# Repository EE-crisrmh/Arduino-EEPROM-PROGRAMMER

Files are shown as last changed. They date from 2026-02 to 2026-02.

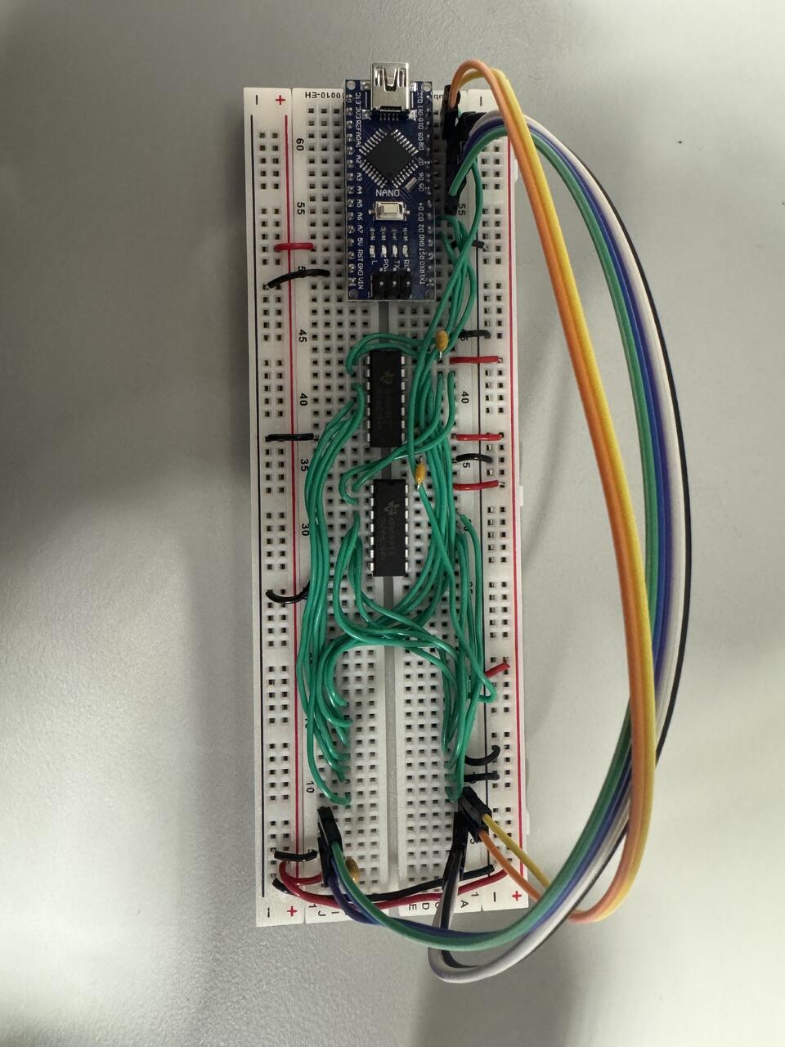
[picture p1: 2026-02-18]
Doc/Prgrammer_Breadboard_Prototype.jpeg

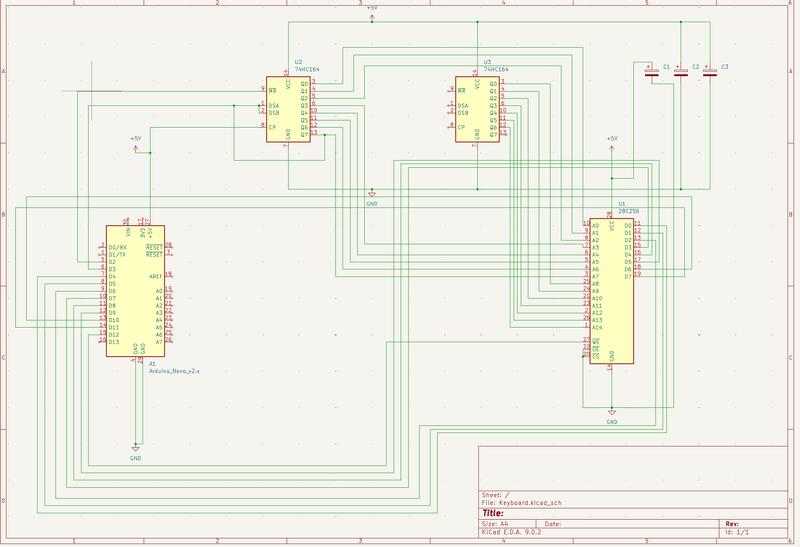
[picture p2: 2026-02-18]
Doc/Schem_pic.jpeg

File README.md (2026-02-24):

# AT28C256 EEPROM Programmer (macOS-friendly)

A standalone EEPROM programmer built to support rapid ROM iteration for a 6502 computer without relying on Windows-only tooling.  
This project uses an **Arduino nano** and **2x shift registers** to drive the EEPROM address bus, perform **parallel byte writes**, and run **read-back verification** to ensure data integrity.

This repo contains:
- The **firmware** that runs on the Arduino and directly controls the EEPROM.
- A **host-side tool spec** (macOS) to upload `.bin` images over USB serial, similar to a minimal “TL48 workflow,” but focused on AT28C256.

---

## Why this exists

I purchased a TL48 programmer but the workflow was not reliable on my macOS. Rather than depend on Windows software, I built a dedicated programmer that:
- Works over standard USB serial
- Supports full-chip programming + verify
- Fits the actual needs of a 6502 ROM development loop

---

## System Architecture

### Hardware (high-level)
- **Arduino Nano** orchestrates all control and timing.
- **Shift registers** generate the full address bus while minimizing GPIO usage.
- **Parallel data bus** is driven directly for byte writes and reads.
- Control signals (WE/OE/CE) are toggled with correct timing for AT28C256 write cycles.

### Firmware responsibilities (Arduino)
The Arduino firmware is responsible for:
- Setting an address (`setAddress(addr)`)
- Writing a byte (`writeByte(addr, value)`)
- Reading a byte (`readByte(addr)`)
- Verifying a block or entire chip (`verify(image)`)

### Host tool responsibilities (macOS)
The host tool is responsible for:
- Loading a ROM image (`.bin`)
- Sending commands/data to the Arduino over USB serial
- Displaying progress + errors
- Optionally doing a second-pass verify for confidence

---

## Features

- **AT28C256 support**
- **Byte-level programming**
- **Read-back verification**
- **Deterministic timing control**
- Designed for a fast ROM iteration loop (edit → build → flash → test)

---

## Host Tool: How a Software Developer can contribute: (More in Future Plans folder) 

The goal is a small CLI tool that feels like:

```bash
eeprom flash firmware.bin
eeprom verify firmware.bin
eeprom read dump.bin
eeprom info

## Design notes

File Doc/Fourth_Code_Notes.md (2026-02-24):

# EEPROM Programmer — Lab Notes

## Date
2026-02-24

---

## Objective
Stabilize the address generation subsystem and migrate the control architecture from Arduino Nano → standalone ATmega328P design for PCB.

---

## What Was Built and Tested

### 1. Breadboard Prototype — 74HC164 Shift Register Chain
- Device: 74HC164 ×2
- Verified functional as a 16-bit shift chain

#### Wiring (per datasheet pinout)
For each 74HC164:
- VCC (14) → +5V
- GND (7) → GND
- CLK (8) → SR_CLK
- CLR (9) → SR_CLR
- A (1) and B (2) tied together

Chain:
- Chip1 QH (13) → Chip2 A+B

Control from MCU:
- SR_DATA → serial data in (chip1 A+B)
- SR_CLK → common clock
- SR_CLR → common clear

Decoupling:
- 0.1 µF per IC

#### Test Method
Firmware patterns:
- Walking 1
- Block fill / flush

#### Result
- Bit propagation confirmed across both ICs
- Visual verification using LEDs on QA outputs
- Chain direction and timing confirmed

---

### 2. ATmega328P Standalone Architecture (Schematic Complete)
- Package: DIP-28
- Programming method: ISP only
- Clock source: internal oscillator (no crystal)

#### Power
- VCC (7), AVCC (20) → +5V
- GND (8), GND (22) → GND
- AREF → 0.1 µF → GND
- 0.1 µF decoupling on VCC and AVCC
- 10 µF bulk on 5V rail

#### Reset
- 10k pull-up to +5V
- Reset pushbutton to GND
- Reset routed to ISP

#### ISP Header (2×3)
- MISO → PB4 (18)
- MOSI → PB3 (17)
- SCK → PB5 (19)
- RESET → pin 1
- VCC, GND

#### Shift Register Control Pins
- SR_DATA → PD2 (pin 4)
- SR_CLK  → PD3 (pin 5)
- SR_CLR  → PD4 (pin 6)

#### Power Input
- External +5V and GND connector
- Bulk cap at entry
- Power LED

#### Debug
- Status LED on PB0

---

## Problems Encountered
- Grid misalignment in KiCad causing false net connectivity
- Hidden power pins in MCU symbol
- Initial clock/data misrouting on shift registers
- Breadboard short during second SR integration → thermal event → corrected by staged reassembly

---

## Verified Working Today
- 16-bit shift chain hardware
- Correct bit propagation
- Clean MCU schematic with ERC passing
- ISP net connectivity

---

## Next Step
Return to breadboard prototype and integrate EEPROM:
- Reintroduce data bus
- Reintroduce /CE /OE /WE control
- Perform address-line validation using proven shift chain

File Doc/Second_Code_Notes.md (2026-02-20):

# Notes — EEPROM Programmer Prototype Debug Log

## Date
2026-02-18

## Goal of today
1) Address shifting works (the EEPROM address changes when I shift different bits)
2) Data bus mapping is correct (D0–D7 are actually the bits I think they are)
3) Writes actually program the EEPROM (not just “I sent a write command”)
4) Reads are stable and repeatable
5) The test interface works reliably (serial commands / batch commands)

## Context
A key complication is that EEPROM I/O3 (data bit 3) is physically broken on my current chip. Because of that, I mask out bit 3 (0x08) during comparisons. This lets me validate the other 7 bits even with the damaged pin.

---

## Test 1 — Baseline read stability at a fixed address
### What I did
I read address `0x0000` repeatedly using the serial read command.

Example:
- `R 0000`
- `R 0000`
- `R 0000`

### What I expected
If address shifting and data reads are stable, the same address should return the same byte every time.

### What I observed
I consistently got a stable value when repeating reads (examples seen during testing included `E7` and later `F7`). The exact value itself is not “good” or “bad” by default — the important part is that it was repeatable for the same address.

### What this told me
- Reads are working at least well enough to return stable bytes.
- Address `0x0000` is being reached consistently (or at minimum the same physical location is being reached consistently).

---

## Test 2 — Spot write + immediate verify (address 0x0000)
### What I did
I attempted to write a known value to address `0x0000` and then read it back.

Example intended sequence:
- `W 0000 AA`
- `R 0000`
- `W 0000 55`
- `R 0000`

Also important: because bit 3 is broken, I compare using a mask:
- expected = written_value & ~0x08
- actual   = read_value & ~0x08

### What I expected
If writes are working, readback should match the written value (except for bit 3 which is masked out).

Examples:
- Write `AA` (10101010) → masked expected `A2`
- Write `55` (01010101) → masked expected `55`

### What I observed
I saw readback values change after writes, which suggests write activity was happening. However, I did not get clean readback equal to the expected masked value. I observed inconsistent results such as `E7`, `F7`, and `67` appearing during different attempts.

### What this told me
- The system can acknowledge a write command (`I ok`), but acknowledgement is not proof of a correct write.
- Something in the write/read path is inconsistent: either bus contention, bit mapping mismatch, timing, or address shifting error during the write cycle.

---

## Test 3 — Full “spot test” in firmware (automatic)
### What I did
I ran the firmware’s automatic spot test (it writes to a small set of addresses and verifies them).

The firmware reported:
- `start spot test`
- `spot FAIL 0 exp=0 got=E7`
- `spot test failed`

### What I expected
Spot test should pass if basic write+read works for a few addresses.

### What I observed
Spot test failed immediately at address `0x0000`: expected `0x00` but got `0xE7`.

### What this told me
The write cycle either did not happen or did not produce correct data. The EEPROM returned whatever was already stored at address 0, or I got corrupted output on the bus.

---

## Test 4 — Serial command interface reliability (single commands)
### What I did
I tested that the Arduino is actually receiving and parsing the command lines correctly.

I enabled debug prints so the Arduino would echo what it received:
- `RX: [R 0000]`

Then I typed a single read command:
- `R 0000`

### What I expected
The Arduino should show it received the correct command and then print a 2-digit hex response.

### What I observed
This worked reliably for single commands.
Example:
- `RX: [R 0000]`
- `F7`

### What this told me
The serial interface works when I send commands one at a time.

---

## Test 5 — Batch command paste behavior (multiple commands pasted at once)
### What I did
I tried to paste multiple lines into Arduino IDE Serial Monitor at once (e.g., the walking-1 pattern or multiple W/R pairs).

### What I expected
Each line would be processed as its own command (like a real terminal).

### What I observed
The Serial Monitor did not reliably deliver each line separately. I saw cases where multiple commands were mashed into one buffer string, resulting in debug output like:
- `RX: [0000 80 R 0000]`
followed by:
- `I err`

### What this told me
Arduino IDE Serial Monitor is not a robust batch sender for this workflow. It can merge, drop, or reformat pasted content depending on line endings and timing.

---

## Test 6 — Firmware changes to handle mashed/pasted command strings
### What I did
I updated the firmware so it can “scavenge” commands from a mashed input string (searching for occurrences of `R ` and `W ` within the received chunk) instead of requiring the command to start at the beginning of the line.

### What I expected
I should be able to paste blocks of commands and have the firmware still execute each `R`/`W` embedded in the input.

### What I observed
After this change, I started getting multiple `I ok` acknowledgements and read outputs in one run, instead of only one action or immediate errors.

However, the write/read results were still inconsistent at the EEPROM level (acknowledgements were not the same as correct readback).

### What this told me
The command transport problem (Serial Monitor batching) can be mitigated in firmware.
But the EEPROM programming correctness problem still remains.

---

## Test 7 — Attempted data bus validation via different write patterns
### What I did
I used different write patterns (e.g., `AA`, `55`, and others) and watched the readback values.

### What I expected
Readback should match the pattern (masked).

### What I observed
Readback changed sometimes, but did not cleanly match the expected masked values, suggesting corruption or bit mapping issues.

### What this told me
The system may be writing, but not correctly / not deterministically.

---

# Summary of what I proved today
✅ I can read stable values from at least some addresses (e.g. repeated reads at 0x0000 return the same byte).  
✅ The firmware can parse single commands reliably.  
✅ Batch/paste behavior can be improved with firmware changes.  
⚠️ Write acknowledgements exist, but I cannot claim reliable programming yet.  
❌ Write + verify is inconsistent and fails the automatic spot test.

---

# What I need to fix

## Electrical (highest priority)
1) **Control OE (and ideally CE) from the Arduino**
   - Right now my control pin strategy can cause the EEPROM to drive the data bus while the Arduino is also driving it during writes.
   - That can cause bus contention and inconsistent programming/readback.
   - On the PCB I need OE on a controllable pin so I can tri-state the EEPROM output during writes.

2) **Data bus direction control discipline**
   - During writes: Arduino drives D0–D7, EEPROM output should be disabled.
   - During reads: Arduino sets D0–D7 as inputs, EEPROM output enabled.

## Firmware fixes
1) **Verify address shifting order is correct (A0–A14 mapping)**
   - Even if reads are stable, I need to confirm I’m truly hitting the intended address lines.
   - I should add a read-only address sweep and compare repeated snapshots for stability.

2) **Improve the write pulse timing**
   - I need to keep WE pulse width within spec and keep address/data stable around the pulse.

3) **Better verification reporting**
   - Print expected vs actual masked bytes.
   - Track which bits mismatch most often to identify wiring errors vs contention.

## Tooling/process fixes
1) **Stop using Arduino IDE Serial Monitor as a batch sender as soon as stable commands are supported**
   - It merges/drops pasted lines.
   - Switch to a serial terminal or a Python script.

2) **Build a dedicated automated tester**
   - Once the hardware control pins are correct, Software team should automate:
     - walking-1 / walking-0 test
     - checkerboard patterns
     - random pattern test with seeded PRNG
     - full-chip write + verify

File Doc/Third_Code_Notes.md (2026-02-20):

# Notes — EEPROM Programmer Prototype Debug Log

## Date
2026-02-19

## Goal of today
Prove whether the prototype can do reliable read + write after adding proper /OE and /CE control (bus contention fix). If it still fails, determine whether the failure is data bus, control lines, or address shifting.

---

## What I changed today (wiring + firmware intent)

### Control pins (active-low)
- Moved EEPROM control from “tied low” to Arduino-controlled:
  - /WE on D12
  - /CE on D5
  - /OE on D6
- Firmware change intent:
  - During writes: disable /OE first so EEPROM never drives the bus while Arduino is driving (prevents contention).
  - During reads: set data pins to INPUT, enable /CE and /OE.

### Data bus mapping (due to pin availability + dead EEPROM bit)
- EEPROM D0..D2 → Arduino A0..A2
- EEPROM D4..D7 → Arduino D8..D11
- EEPROM D3 (bit 3) is physically broken → always mask bit 3 in write/read/compare

---

## Tests run today, why they were run, and what they proved

### Test 1 — “Why do I read the same byte everywhere?”
**Observation:** reads returned `0x77` for many addresses (ex: R 0000, R 0001, R 00FF all returned 77).

**Why run this test:** If the value is constant across different addresses, either:
- the address is not changing (address shifter chain dead), OR
- the data bus is stuck/floating and not actually reading EEPROM output.

**What it proved:** By itself, constant reads do not prove which subsystem is broken. It triggered the next tests.

---

### Test 2 — DMM check of EEPROM data pins during read
Measured at EEPROM pins while a read was happening:
- D0 ≈ 0.227 V
- D4 ≈ 0.239 V
- D7 ≈ 0.204 V

**Why run this test:** Compare “what firmware thinks it reads” vs actual physical voltages at EEPROM pins.

**What it proved:** The physical data pins looked LOW while firmware still reported `0x77`, which strongly suggested either:
- the bit-to-pin mapping is wrong somewhere, OR
- the bus is not being read from the EEPROM pins we think it is.

---

### Test 3 — Bus “float vs driven” test (EEPROM disabled vs enabled)
A dedicated sketch printed bus values in two states:

- EEPROM disabled: `/CE=HIGH` and `/OE=HIGH` → bus should float  
- EEPROM enabled: `/CE=LOW` and `/OE=LOW` → EEPROM should drive bus

**Result example:**
- `CE=H OE=H 36   CE=L OE=L 77`

**Why run this test:** It isolates whether the EEPROM is influencing the bus at all.

**What it proved:**
- The bus changes between disabled vs enabled → EEPROM output enable path is doing something.
- But the enabled value being constant across addresses still points to address lines not changing.

---

### Test 4 — Address toggle test (read 0x0000 vs 0x1234 repeatedly)
A test sketch repeatedly read two different addresses:

- Expected: values should differ most of the time if addresses are changing.
- Actual: `0000=77  1234=77` repeatedly.

**Why run this test:** It directly checks whether the address shifter chain is changing the EEPROM address.

**What it proved:** Address lines were not changing at the EEPROM (or not reaching it). This is an address path problem, not a write-timing problem.

---

### Test 5 — 74HC164 single-chip LED shift test
Built a minimal test:
- One 74HC164 only
- /MR tied to +5V
- CP clocked from Arduino
- Serial data from Arduino
- LED on Q0

**Observation:** LED blinked as expected.

**Why run this test:** Prove that the Arduino clock/data pins and at least one shift register are functional.

**What it proved:** The base shift register logic works (chip 1 is alive and shifts correctly).

---

### Test 6 — 74HC164 two-chip chained LED shift test (16-bit)
Chained the second 74HC164:
- Chip 2 inputs driven from chip 1 Q7
- Same clock to both
- /MR tied high for both
- LED on chip 2 output

**Observation:** LED blinked on chip 2 as expected.

**Why run this test:** Prove the 16-bit shift chain (chip1 → chip2) actually propagates data.

**What it proved:** The shift chain itself can work in isolation.

---

## Current conclusion (end of session)
- Data bus control (/OE, /CE) is conceptually correct and bus state changes when enabling/disabling the EEPROM.
- 74HC164 chain can shift data (verified with LED tests).
- Reads returning `0x77` at all addresses strongly implies: **EEPROM address pins are not being driven by the shift register outputs, or not wired correctly to the EEPROM address pins.**
- The remaining work is hardware integration: connecting 74HC164 Q outputs to EEPROM A0–A14 correctly and verifying the address lines change at the EEPROM pins.

---

## Next session test plan (what to test next)

### Priority 1 — prove address pins change at the EEPROM
Run address toggle (0x0000 vs 0x0001, then 0x0000 vs 0x7FFF) and measure directly at EEPROM pins:
- A0 should toggle when switching 0x0000 ↔ 0x0001
- A1 should stay constant in that same test
- For 0x0000 ↔ 0x7FFF, multiple address pins should change

If A0–A14 don’t change at the EEPROM pins, fix the wiring between shift-register outputs and EEPROM address inputs.

### Priority 2 — verify /CE and /OE at the EEPROM pins
Measure voltages directly at the EEPROM pins during read:
- /CE near 0V
- /OE near 0V
If they’re not, wiring to EEPROM control pins is wrong.

### Priority 3 — re-run address toggle read test
Once A-lines are confirmed changing at EEPROM pins:
- rerun `0000` vs `1234` read test; values should differ.
- rerun float-vs-driven test; driven value should depend on address.

### Priority 4 — restore write/verify
Only after reads vary with address:
- rerun spot test
- then full write + verify
- track bit error counts (excluding dead bit 3)

---

## Known risks / things left to test
- Incorrect mapping of 74HC164 outputs (Q0..Q7) to EEPROM A0..A7 / A8..A14
- Breadboard row/rail breaks causing address lines not actually connected
- Wrong assumption about which physical pins are Q7 / A0 etc (pinout mismatch)
- EEPROM /CE and /OE not actually reaching EEPROM pins (measured at wrong node previously)

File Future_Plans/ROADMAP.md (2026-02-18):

## Phase 1 — Software polish (macOS-first)

### Goals
- A reliable CLI tool to flash/verify/read EEPROM images over USB-serial
- A stable, versioned serial protocol between host and Arduino
- Clear errors, retries, and progress reporting

### Deliverables
- `host/` CLI tool with commands:
  - `flash <file.bin>`
  - `verify <file.bin>`
  - `read <out.bin>`
  - `info`
- Protocol document + firmware implementing it
- Simple release packaging (macOS)

---

## Phase 2 — PCB version

### Goals
- Replace breadboard/wiring with a manufacturable PCB
- Improve reliability, connectors, labeling, and testability

### Deliverables
- PCB schematic + layout files
- BOM
- Assembly notes + validation checklist

---

## Phase 3 — Quality upgrades 
- Better performance (chunking, smarter verify)
- Expanded chip support (same voltage family)
- Optional GUI wrapper

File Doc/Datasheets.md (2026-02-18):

https://www.ti.com/lit/ds/symlink/sn74hc164.pdf
https://ww1.microchip.com/downloads/en/DeviceDoc/Atmel-7810-Automotive-Microcontrollers-ATmega328P_Datasheet.pdf
https://www.alldatasheet.com/datasheet-pdf/view/56115/ATMEL/AT28C256.html

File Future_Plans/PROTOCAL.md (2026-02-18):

# Serial Protocol (Draft)

## Transport
- USB serial
- Default: 115200 baud (can be changed)
- Newline-delimited ASCII headers + optional binary payload
- All multi-byte numbers are HEX in ASCII headers

## Responses
- `OK <message>`
- `ERR <code> <message>`
- `DATA <len>` followed by raw bytes
- `ACK <seq>`
- `NAK <seq> <reason>`

## Commands

### INFO
Host:
- `INFO\n`
Device:
- `OK PROTO=1 FW=<ver> CHIP=28C256 SIZE=32768 CHUNK=256\n`

### WRITE (chunked)
Host:
- `WRITE <addr> <len> <seq> <crc32>\n`
- then `<len>` raw bytes
Device:
- `ACK <seq>\n` or `NAK <seq> <reason>\n`

### READ
Host:
- `READ <addr> <len>\n`
Device:
- `DATA <len>\n` then `<len>` raw bytes then `OK\n`

### VERIFY (optional shortcut)
Host:
- `VERIFY <addr> <len> <seq> <crc32>\n`
- then `<len>` raw bytes
Device:
- `ACK <seq>\n` or `ERR MISMATCH <addr> EXP=<xx> GOT=<yy>\n`

## Notes
- Chunk size default: 256 bytes
- Host should retry NAK/timeouts up to N times, then fail
- Firmware must reject out-of-range addr/len

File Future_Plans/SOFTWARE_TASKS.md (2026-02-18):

# Software Tasks (Host + Firmware)

This document describes what a software contributor needs to implement to make the programmer feel like a real tool on macOS.

## Required skills
- Comfortable in terminal
- Python experience
- Serial communication (USB CDC / `/dev/cu.*`)
- Handling binary files (`.bin`)
- Basic error handling and packaging

---

## 1) Define and implement a robust serial protocol
### Goal
Host and Arduino communicate with clear commands, responses, checksums, and retries.

### Requirements
- Versioned protocol (`PROTO 1`)
- Chunked transfers (e.g., 256 bytes per chunk)
- Per-chunk checksum (CRC32 or simple checksum)
- Explicit ACK/NAK responses
- Timeouts + retry strategy
- Useful error codes/messages

Deliverables:
- `future-plans/PROTOCOL.md` finalized
- Firmware implements the protocol
- Host tool uses the protocol

---

## 2) Build a macOS CLI tool
### Commands
- `eeprom info`
  - prints device + firmware version + supported chip geometry
- `eeprom flash <file.bin> [--verify]`
  - writes file to EEPROM, optional verify (default verify recommended)
- `eeprom verify <file.bin>`
  - compares EEPROM contents to file
- `eeprom read <out.bin>`
  - dumps EEPROM contents to a file

### CLI requirements
- Auto-detect serial port (or allow `--port`)
- Progress bar (bytes written / total)
- Clear failures (first mismatch address, expected vs actual)
- Exit codes suitable for automation

Deliverables:
- `host/` folder with CLI implementation
- `README` usage examples
- Basic unit tests for file/protocol parsing

---

## 3) Firmware improvements for reliability
### Requirements
- Input validation (address range, length)
- Deterministic state machine (no “random blocking waits”)
- Configurable timing constants for AT28C256
- Optional “verify while writing” mode

Deliverables:
- Firmware refactor for clean command handling
- Logging hooks (optional)

---

## 4) Packaging / distribution (macOS)
Pick one:
- Python + `pipx` install instructions
- Single-file Python script with minimal deps
- Go single-binary release (best UX)

Deliverables:
- Install instructions
- Tagged release artifacts (optional)

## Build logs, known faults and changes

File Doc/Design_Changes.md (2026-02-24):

# Architecture Revision — EEPROM Programmer

## Core Change
Migration from Arduino Nano control → dedicated ATmega328P system.

---

## Why
Previous prototype limitations:
- Pin contention
- Hard to scale for PCB
- Control timing tied to Arduino board layout

New design:
- Deterministic pin mapping
- ISP programmable
- Internal clock → fewer components
- PCB-ready architecture

---

## Address Generation Strategy
Unchanged electrically, but now MCU-native:

74HC164 ×2 → 16-bit serial address loader

Advantages:
- Minimal MCU pin usage
- Deterministic update timing
- Direct PCB routing to EEPROM address bus

---

## Control Signal Strategy

### Shift Registers
- SR_DATA (PD2)
- SR_CLK  (PD3)
- SR_CLR  (PD4)

### Reserved for ISP (do not use for GPIO)
- PB3 MOSI
- PB4 MISO
- PB5 SCK

---

## Power Strategy
External regulated +5V input:
- Bulk capacitor at entry
- Local decoupling per IC
- Power LED for bring-up verification

---

## Reset Strategy
- Hardware pull-up
- Manual pushbutton
- ISP-controlled reset

---

## Debug Strategy
Test points for:
- SPI programming
- Shift register control lines
- Power rails

Status LED on PB0 for firmware validation.

---

## Clock Strategy
Internal oscillator:
- No crystal
- Fewer parts
- Purpose-built for programmer firmware

---

## Result
Modular, testable, PCB-safe control platform for EEPROM interface.

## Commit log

2026-02-18 Update and rename schematic.kicad_s to EEPROM_PROGRAMMER_testcode
2026-02-20 Create LED_test_code
2026-02-20 Create LED_testcode_U3connections
2026-02-24 Add files via upload
    Schematic design without EEPROM
